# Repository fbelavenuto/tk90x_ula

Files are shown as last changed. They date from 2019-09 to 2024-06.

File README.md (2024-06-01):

# Projeto ULA CPLD - Clone da ULA do TK90X/TK95.

Este projeto se destina a substituir um componente feito sob medida para o microcomputador de 8 bits modelo TK90X e TK95, fabricado pela empresa brasileira Microdigital na década de 1980. O TK90X/TK95 é um clone do ZX Spectrum fabricado pela empresa inglesa Sinclair Research.

# Copyright

Copyright Fábio Belavenuto 2012.
Copyright Victor Trucco 2012.

# Licença

This documentation describes Open Hardware and is licensed under the CERN OHL v. 1.1.
You may redistribute and modify this documentation under the terms of the
CERN OHL v.1.1. (http://ohwr.org/cernohl). This documentation is distributed
WITHOUT ANY EXPRESS OR IMPLIED WARRANTY, INCLUDING OF MERCHANTABILITY,
SATISFACTORY QUALITY AND FITNESS FOR A PARTICULAR PURPOSE.
Please see the CERN OHL v.1.1 for applicable conditions

# Detalhes

Todo este trabalho foi baseado no trabalho do Chris Smith [1] e feito em conjunto pelos autores do projeto. Agradecimentos ao pessoal das listas de discussão brasileiras "ClubedoTK" [2] e "TK90X" [3] que incentivaram e ajudaram no desenvolvimento deste projeto.

No site [4] há um pequeno diário criado pelo Victor Trucco descrevendo os passos durante o desenvolvimento do projeto.

O projeto tem duas revisões, rev1 e rev2, cada uma delas em uma pasta separada. Em cada revisão existem uma pasta com o design da PCB, uma pasta com os aqruivos de fabricação Gerber e uma pasta com o projeto do código-fonte do CPLD. A versão do software utilizado para o design da PCB foi o Cadsoft Eagle e o software utilizado para o design do CPLD foi o Altera Quartus versão 10.1sp1.
  
Na pasta "VHDL Version" há uma versão do código do CPLD toda escrita em VHDL, tanto para CPLDs da Altera e CPLDs da Xilinx. Este código não foi usado no CPLD da ULA final.

Para a revisão 1, o arquivo [Pinout jumpers.jpg] "rev1/Pinout jumpers.jpg" mostra a pinagem dos jumpers e saída RGB contidas na PCB. Para a revisão 2 o mesmo pinout pode ser utilizado, porém a seleção do tipo de sincronismo é feita por jumpers de solda.

O produto final é uma placa pequena feita para ser inserida diretamente no soquete do circuito integrado original, substituindo assim o componente defeituoso, com a vantagem de ter uma saída RGB analógica em 15KHz para ser usado diretamente em monitores compatíveis.

A temporização deste projeto chega a 99% de fidelidade ao componente original.

# Montagem

Para a montagem da PCB, acesse [este](https://fbelavenuto.github.io/pages/ULA-rev1-ibom.html) link para BOM interativo da revisão 1 e [este](https://fbelavenuto.github.io/pages/ULA-rev2-ibom.html) para a revisão 2.

Solde os componentes SMD, consiga uma barra de terminais torneado de 80 pinos, corte-a no meio para os dois lados de 40 pinos. O CPLD ocupa o espaço de quatro pinos da barra de terminais torneada de cada lado, então é necessário cortar os 4 pinos centrais de cada barra para fazer uma soldagem em SMD nestes pontos.

Coloque a barra no lugar para descobrir quais os pinos devem ser cortados, corte com um alicate de corte fino para deixar rente à PCB. Utilize um soquete torneado de 40 pinos e plugue as barras no soquete, para uma soldagem alinhada. Coloque a PCB em cima da barra e encaixe os pinos não cortados nos seus respectivos furos e solde-os. Para soldar os 8 pinos cortados (4 de cada lado) coloque a ponta de ferro em um lado para aquecer a PCB e a barra de pinos ao mesmo tempo e coloque o estanho pelo outro lado. Confira com uma lente se a solda foi bem sucedida.

Se for utilizar a saída RGB 15KHz solde uma barra de pinos 90 graus na PCB, e na revisão 2 solde o jumper de solda do tipo de sincronismo. É possível escolher qual tipo de sincronismo irá para o monitor, separado ou composto. Dependendo do monitor um tipo poderá ser melhor que o outro, então pode ser necessário testar os dois tipos, porém a opção de sincronismo separado tem mais compatibilidade com os monitores.

Na pasta [Fotos](rev1/Fotos/) há algumas fotos do primeiro protótipo construido.

# Programação do CPLD

Para programar o CPLD é necessário um dispositivo USB Blaster específico para os CPLDs da Altera. Na PCB rev1 os pontos de contato dos sinais de programação estão espalhados pela PCB, sendo necessário a construção de uma "cama de pregos" ou a soldagem de fios nos pontos. Para a rev2 os sinais estão dispostos em um conector 1x6. O nome dos sinais estão no silkscreen da PCB. É necessário utilziar uma fonte externa de 5V e jogar 5V no pino VCC do USB Blaster, pois este não alimenta o dispositivo mas detecta se ele está alimentado.

Abra o projeto no software Quartus e vá até o programador. Alimente a PCB e o USB Blaster e clique em "Program". Caso haja falha neste passo cheque as conexões e cheque se está indo os 5V para o USB Blaster. O arquivo necessário para programar se chama "ULA.pof".

# Uso

É altamente recomendável a troca do soquete da ULA na PCB do TK90X/95 por um soquete torneado, porém é possível utilizar o original. Plugue com cuidado a PCB da ULA no soquete do TK, vá pressionando devagar para não entortar nenhum pino. Se tudo ocorrer bem é só ligar o micro e curtir a sua nova ULA.

Se for utilizar a saída RGB 15KHz construa um cabo com um conector DE-15 para ligar nos pinos de saída RGB conforme descrito [nesta](rev1/Pinout%20jumpers.jpg) imagem.

# Links

[1] http://www.zxdesign.info/thebeginning.shtml
[2] http://br.groups.yahoo.com/group/ClubedoTK/
[3] http://br.groups.yahoo.com/group/TK90X/
[4] http://www.victortrucco.com/TK/ULATKCPLD/ULATKCPLD.asp

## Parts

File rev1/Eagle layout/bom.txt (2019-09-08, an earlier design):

Partlist 

Qty Value       Device         Package  Parts              Description                
2   100n        C-EUC1206K     C1206K   C1, C2             CAPACITOR, European symbol 
3   100         R-EU_M0805     M0805    R1, R2, R3         RESISTOR, European symbol  
3   1k5         R-EU_M0805     M0805    R4, R5, R6         RESISTOR, European symbol  
1   10K         R-EU_M0805     M0805    R7                 RESISTOR, European symbol  
1   EPM7128     EPM7128-T100   TQFP100  IC1                EPM70128                   
1   Soquete ULA DIL40          DIL40    IC2                Dual In Line               
1   4050D       4050D          SO16     IC3                Hex non-inverting BUFFER   
1               MA06-11        MA06-1-1 SV1                PIN HEADER                 
4   SELSYNC     MA03-1MA03-1-1 MA03-1-1 SJ1                PIN HEADER

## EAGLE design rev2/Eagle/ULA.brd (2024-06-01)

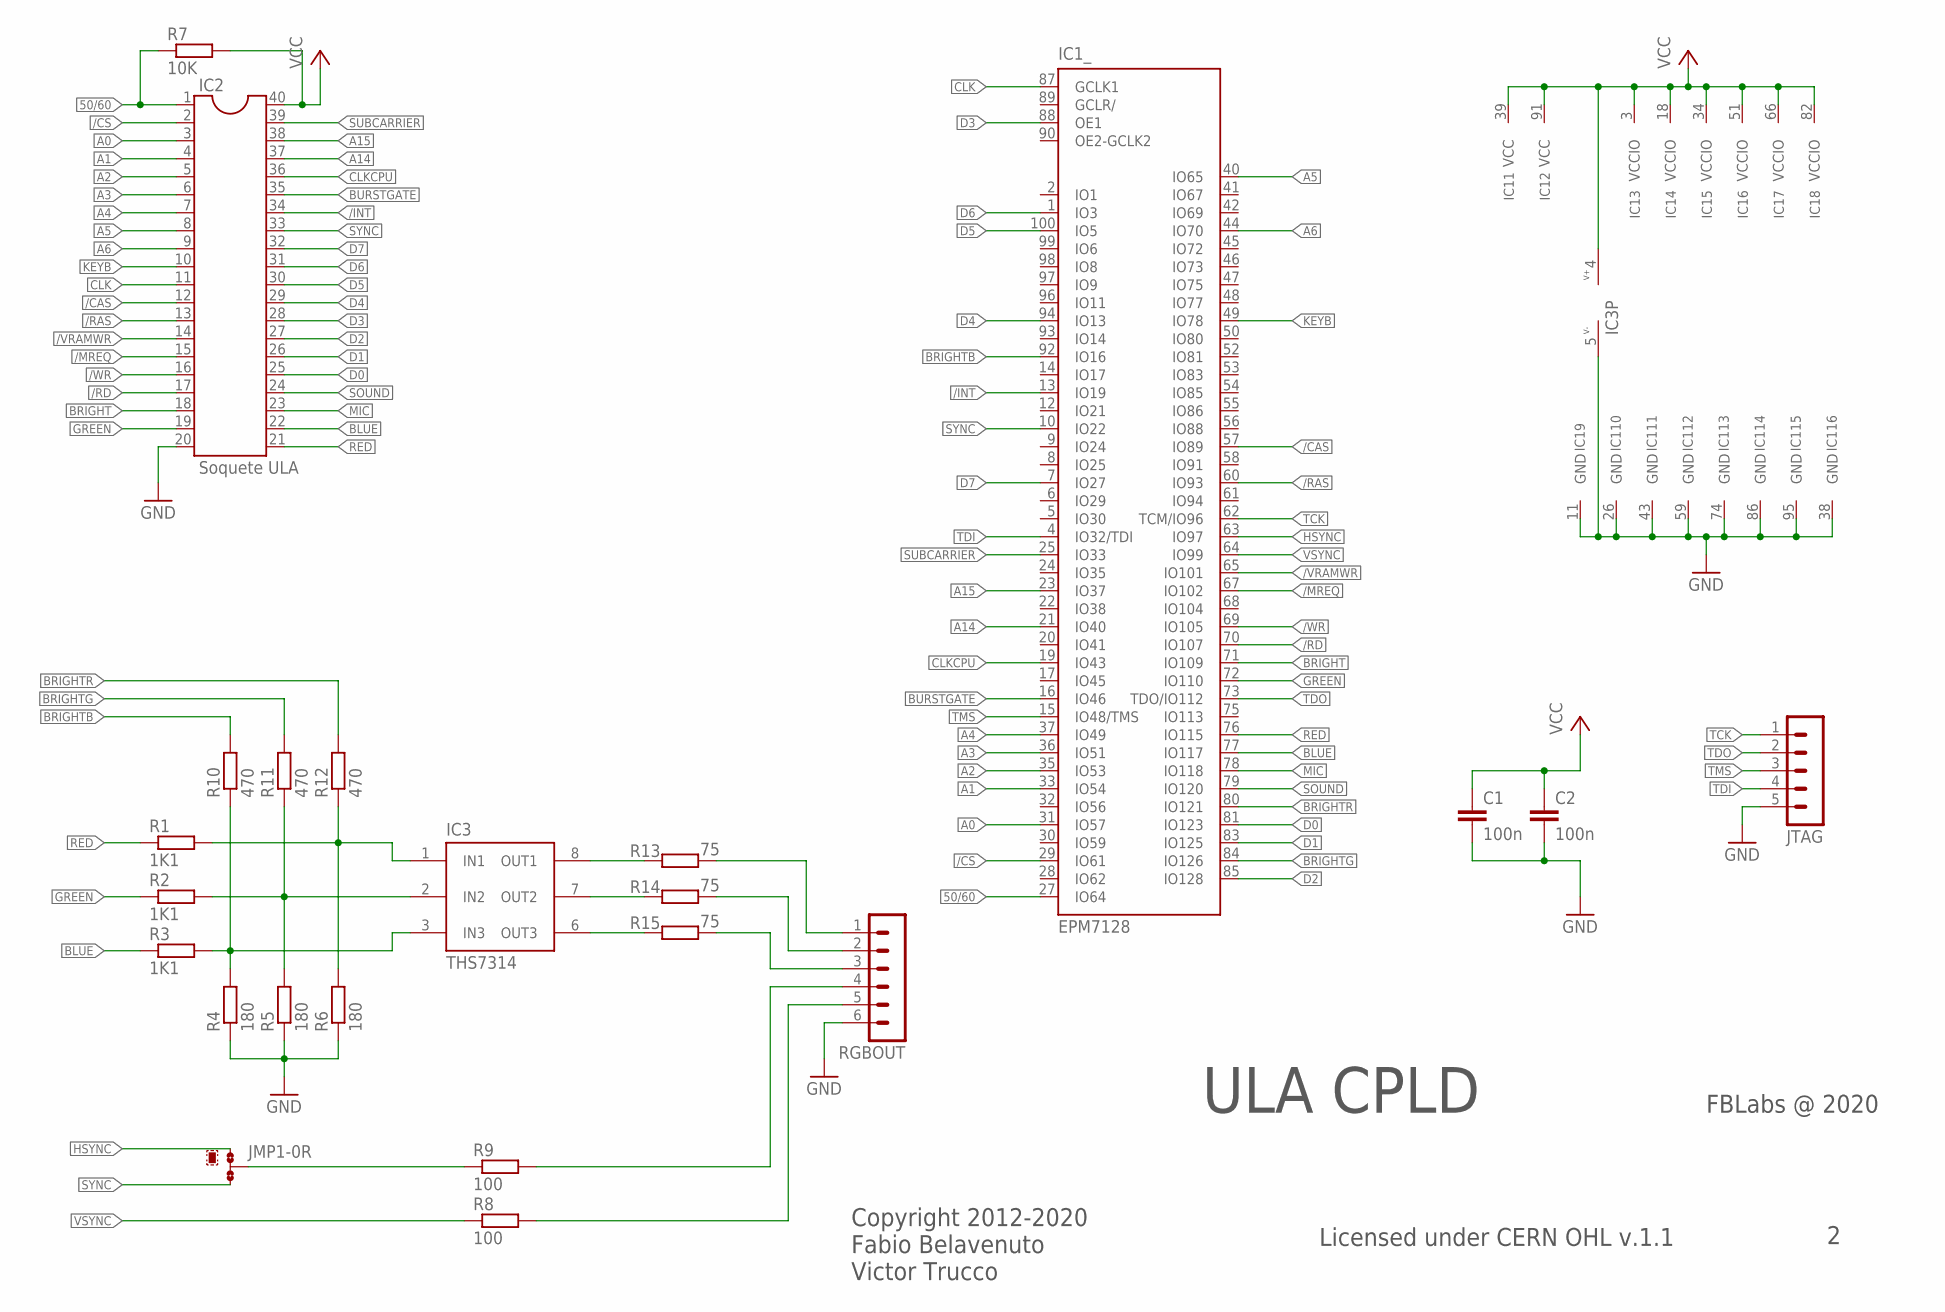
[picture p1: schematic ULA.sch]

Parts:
C1, C2: 100n; C1206
IC1: EPM7128; TQFP100
IC2: Soquete ULA; DIL40
IC3: THS7314; SOIC8
JMP1: 0R-JUMPA; A0R-JMP
JTAG: MA05-1
R1, R2, R3: 1K1; M0805
R4, R5, R6: 180; M0805
R7: 10K; M0805
R8, R9: 100; M0805
R10, R11, R12: 470; M0805
R13, R14, R15: 75; M0805
RGBOUT: MA06-1

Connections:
50/60: IC1.27 (IO64), IC2.1, R7.1
/CAS: IC1.57 (IO89), IC2.12
/CS: IC1.29 (IO61), IC2.2
/INT: IC1.13 (IO19), IC2.34
/MREQ: IC1.67 (IO102), IC2.15
/RAS: IC1.60 (IO93), IC2.13
/RD: IC1.70 (IO107), IC2.17
/VRAMWR: IC1.65 (IO101), IC2.14
/WR: IC1.69 (IO105), IC2.16
A0: IC1.31 (IO57), IC2.3
A1: IC1.33 (IO54), IC2.4
A2: IC1.35 (IO53), IC2.5
A3: IC1.36 (IO51), IC2.6
A4: IC1.37 (IO49), IC2.7
A5: IC1.40 (IO65), IC2.8
A6: IC1.44 (IO70), IC2.9
A14: IC1.21 (IO40), IC2.37
A15: IC1.23 (IO37), IC2.38
BLUE: IC1.77 (IO117), IC2.22, R3.1
BRIGHT: IC1.71 (IO109), IC2.18
BRIGHTB: IC1.92 (IO16), R10.2
BRIGHTG: IC1.84 (IO126), R11.2
BRIGHTR: IC1.80 (IO121), R12.2
BURSTGATE: IC1.16 (IO46), IC2.35
CLK: IC1.87 (GCLK1), IC2.11
CLKCPU: IC1.19 (IO43), IC2.36
D0: IC1.81 (IO123), IC2.25
D1: IC1.83 (IO125), IC2.26
D2: IC1.85 (IO128), IC2.27
D3: IC1.88 (OE1), IC2.28
D4: IC1.94 (IO13), IC2.29
D5: IC1.100 (IO5), IC2.30
D6: IC1.1 (IO3), IC2.31
D7: IC1.7 (IO27), IC2.32
GND: C1.2, C2.2, IC1.11 (GND), IC1.26 (GND), IC1.38 (GND), IC1.43 (GND), IC1.59 (GND), IC1.74 (GND), IC1.86 (GND), IC1.95 (GND), IC2.20, IC3.5 (V-), JTAG.5, R4.1, R5.1, R6.1, RGBOUT.6
GREEN: IC1.72 (IO110), IC2.19, R2.1
HSYNC: IC1.63 (IO97), JMP1.1
KEYB: IC1.49 (IO78), IC2.10
MIC: IC1.78 (IO118), IC2.23
unnamed: R15.2, RGBOUT.3
unnamed: R14.2, RGBOUT.2
unnamed: R13.2, RGBOUT.1
unnamed: IC3.3 (IN3), R3.2, R4.2, R10.1
unnamed: IC3.2 (IN2), R2.2, R5.2, R11.1
unnamed: IC3.6 (OUT3), R15.1
unnamed: IC3.7 (OUT2), R14.1
unnamed: IC3.8 (OUT1), R13.1
unnamed: IC3.1 (IN1), R1.2, R6.2, R12.1
unnamed: JMP1.2, R9.1
unnamed: R9.2, RGBOUT.4
unnamed: R8.2, RGBOUT.5
RED: IC1.76 (IO115), IC2.21, R1.1
SOUND: IC1.79 (IO120), IC2.24
SUBCARRIER: IC1.25 (IO33), IC2.39
SYNC: IC1.10 (IO22), IC2.33, JMP1.3
TCK: IC1.62 (TCM/IO96), JTAG.1
TDI: IC1.4 (IO32/TDI), JTAG.4
TDO: IC1.73 (TDO/IO112), JTAG.2
TMS: IC1.15 (IO48/TMS), JTAG.3
VCC: C1.1, C2.1, IC1.3 (VCCIO), IC1.18 (VCCIO), IC1.34 (VCCIO), IC1.39 (VCC), IC1.51 (VCCIO), IC1.66 (VCCIO), IC1.82 (VCCIO), IC1.91 (VCC), IC2.40, IC3.4 (V+), R7.2
VSYNC: IC1.64 (IO99), R8.1

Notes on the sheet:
ULA CPLD
Licensed under CERN OHL v.1.1
Copyright 2012-2020 Fabio Belavenuto Victor Trucco
FBLabs @ 2020

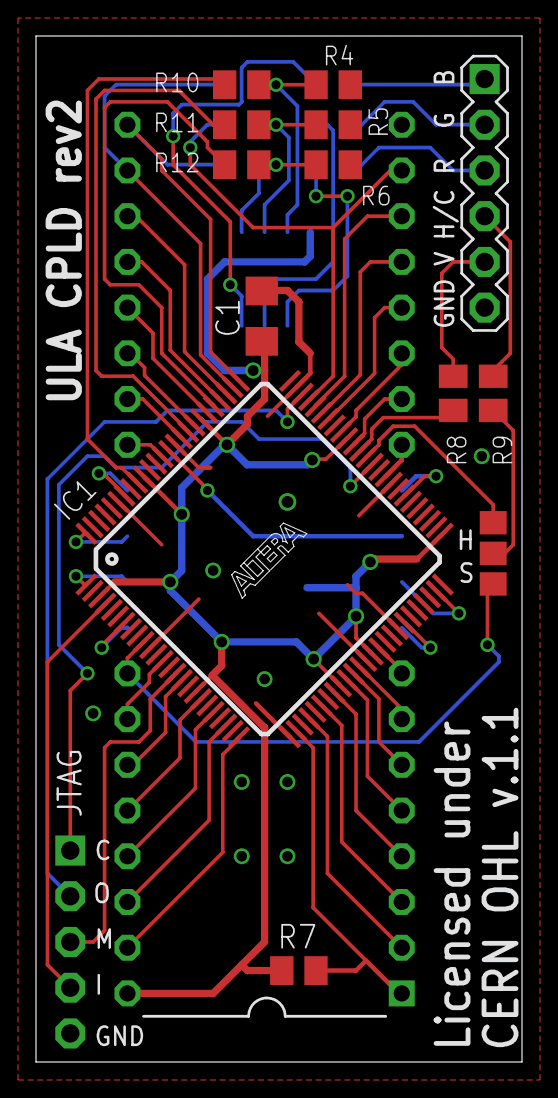
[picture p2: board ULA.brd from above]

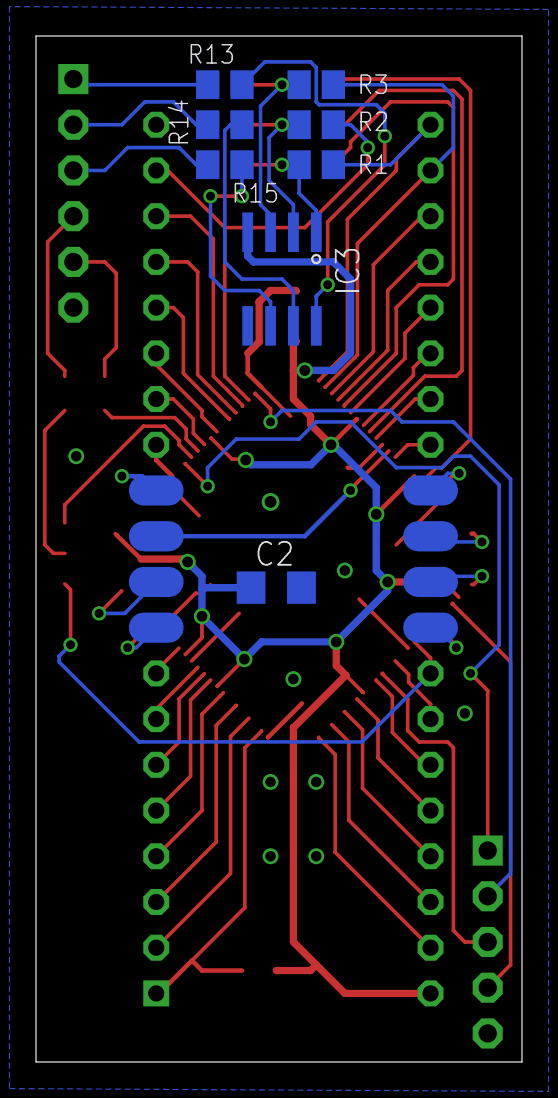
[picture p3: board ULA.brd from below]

Board: 2 copper layers, 27.0 x 57.0 mm, 23 parts (8 on the bottom side), 61 nets.

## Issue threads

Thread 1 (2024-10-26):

ULA Spectrum

FranTerrassa, 2024-10-26:
Olá, ótimo trabalho. Acho ótimo que essa contribuição seja feita para a comunidade. Entendo que este ULA é para um clone do espectro. Poderia funcionar como ULA em um spextrum zx?
Desculpe se não entendi muito bem, estou usando o Google Tradutor.
Saudações,

taupter, 2024-10-29:
Hello. Sadly Fabio Belavenuto took his own life this month. He was a great mind and a great friend that succumbed to depression.
Yes, this ULA can substitute the Ferranti one. It can be configured to work in 50Hz (UK) or 60Hz (PAL-M).

FranTerrassa, 2024-10-29:
ostras!!! você me deixou pedra. Lamento muito ouvir isso, minhas sinceras condolências...

FranTerrassa, 2024-11-21:
> Hola. Lamentablemente Fabio Belavenuto se quitó la vida este mes. Era una gran mente y un gran amigo que sucumbió a la depresión. Sí, este ULA puede sustituir al de Ferranti. Se puede configurar para que funcione en 50 Hz (Reino Unido) o 60 Hz (PAL-M).

como devo fazer isso???

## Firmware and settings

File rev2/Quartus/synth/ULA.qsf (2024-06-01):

# -------------------------------------------------------------------------- #
#
# Copyright (C) 1991-2011 Altera Corporation
# Your use of Altera Corporation's design tools, logic functions 
# and other software and tools, and its AMPP partner logic 
# functions, and any output files from any of the foregoing 
# (including device programming or simulation files), and any 
# associated documentation or information are expressly subject 
# to the terms and conditions of the Altera Program License 
# Subscription Agreement, Altera MegaCore Function License 
# Agreement, or other applicable license agreement, including, 
# without limitation, that your use is for the sole purpose of 
# programming logic devices manufactured by Altera and sold by 
# Altera or its authorized distributors.  Please refer to the 
# applicable agreement for further details.
#
# -------------------------------------------------------------------------- #
#
# Quartus II 64-Bit
# Version 10.1 Build 197 01/19/2011 Service Pack 1 SJ Web Edition
# Date created = 20:05:27  May 17, 2013
#
# -------------------------------------------------------------------------- #
#
# Notes:
#
# 1) The default values for assignments are stored in the file:
#		ULA_assignment_defaults.qdf
#    If this file doesn't exist, see file:
#		assignment_defaults.qdf
#
# 2) Altera recommends that you do not modify this file. This
#    file is updated automatically by the Quartus II software
#    and any changes you make may be lost or overwritten.
#
# -------------------------------------------------------------------------- #


set_global_assignment -name FAMILY MAX7000S
set_global_assignment -name DEVICE "EPM7128STC100-15"
set_global_assignment -name TOP_LEVEL_ENTITY ULA
set_global_assignment -name ORIGINAL_QUARTUS_VERSION "10.1 SP1"
set_global_assignment -name PROJECT_CREATION_TIME_DATE "20:05:27  MAY 17, 2013"
set_global_assignment -name LAST_QUARTUS_VERSION "13.0 SP1"
set_global_assignment -name DEVICE_FILTER_PACKAGE TQFP
set_global_assignment -name DEVICE_FILTER_PIN_COUNT 100
set_global_assignment -name ERROR_CHECK_FREQUENCY_DIVISOR 1702130533
set_global_assignment -name MIN_CORE_JUNCTION_TEMP 0
set_global_assignment -name MAX_CORE_JUNCTION_TEMP 85
set_global_assignment -name EDA_SIMULATION_TOOL "ModelSim-Altera (VHDL)"
set_global_assignment -name EDA_OUTPUT_DATA_FORMAT VHDL -section_id eda_simulation
set_global_assignment -name MAX7000_DEVICE_IO_STANDARD TTL
set_global_assignment -name PROJECT_OUTPUT_DIRECTORY output_files
set_global_assignment -name BDF_FILE ../src/Wait_Subcarrier.bdf
set_global_assignment -name BDF_FILE ../src/ULA.bdf
set_global_assignment -name BDF_FILE ../src/Porta254.bdf
set_global_assignment -name BDF_FILE ../src/HSync_Blank.bdf
set_global_assignment -name BDF_FILE ../src/DRAM_CAS_RAS.bdf
set_global_assignment -name BDF_FILE ../src/DRAM_ADDRESS.bdf
set_global_assignment -name BDF_FILE ../src/Display.bdf
set_global_assignment -name BDF_FILE ../src/clock.bdf
set_global_assignment -name VERILOG_FILE ../src/interrupcao2.v
set_global_assignment -name VERILOG_FILE ../src/counter_9bit.v
set_global_assignment -name VERILOG_FILE ../src/counter_13bit.v
set_global_assignment -name VERILOG_FILE ../src/counter_12bit.v
set_global_assignment -name VERILOG_FILE ../src/counter_10bit.v
set_global_assignment -name VHDL_FILE ../src/VSync2.vhd
set_global_assignment -name VHDL_FILE ../src/VoutGen.vhd
set_location_assignment PIN_7 -to d[7]
set_location_assignment PIN_1 -to d[6]
set_location_assignment PIN_100 -to d[5]
set_location_assignment PIN_94 -to d[4]
set_location_assignment PIN_88 -to d[3]
set_location_assignment PIN_85 -to d[2]
set_location_assignment PIN_83 -to d[1]
set_location_assignment PIN_81 -to d[0]
set_location_assignment PIN_27 -to PINO1_60/50Hz
set_location_assignment PIN_29 -to PINO2_/CS
set_location_assignment PIN_31 -to PINO3_A0
set_location_assignment PIN_33 -to PINO4_A1
set_location_assignment PIN_35 -to PINO5_A2
set_location_assignment PIN_36 -to PINO6_A3
set_location_assignment PIN_37 -to PINO7_A4
set_location_assignment PIN_40 -to PINO8_A5
set_location_assignment PIN_44 -to PINO9_A6
set_location_assignment PIN_49 -to PINO10_KEYBOARD
set_location_assignment PIN_87 -to PINO11_CLK
set_location_assignment PIN_57 -to PINO12_/CAS
set_location_assignment PIN_60 -to PINO13_/RAS
set_location_assignment PIN_65 -to PINO14_/VRAMWR
set_location_assignment PIN_67 -to PINO15_/MREQ
set_location_assignment PIN_69 -to PINO16_/WR
set_location_assignment PIN_70 -to PINO17_/RD
set_location_assignment PIN_71 -to PINO18_BRIGHT
set_location_assignment PIN_72 -to PINO19_GREEN
set_location_assignment PIN_76 -to PINO21_RED
set_location_assignment PIN_77 -to PINO22_BLUE
set_location_assignment PIN_78 -to PINO23_MIC
set_location_assignment PIN_79 -to PINO24_SOUND
set_location_assignment PIN_10 -to PINO33_SYNC
set_location_assignment PIN_13 -to PINO34_/INT
set_location_assignment PIN_16 -to PINO35_BURSTGATE
set_location_assignment PIN_19 -to PINO36_CLKCPU
set_location_assignment PIN_21 -to PINO37_A14
set_location_assignment PIN_23 -to PINO38_A15
set_location_assignment PIN_25 -to PINO39_SUBCARRIER
set_location_assignment PIN_63 -to _HSYNC
set_location_assignment PIN_64 -to _VSYNC
set_location_assignment PIN_92 -to BRIGHTB
set_location_assignment PIN_84 -to BRIGHTG
set_location_assignment PIN_80 -to BRIGHTR

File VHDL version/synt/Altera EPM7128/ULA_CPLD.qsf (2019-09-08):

# -------------------------------------------------------------------------- #
#
# Copyright (C) 1991-2013 Altera Corporation
# Your use of Altera Corporation's design tools, logic functions 
# and other software and tools, and its AMPP partner logic 
# functions, and any output files from any of the foregoing 
# (including device programming or simulation files), and any 
# associated documentation or information are expressly subject 
# to the terms and conditions of the Altera Program License 
# Subscription Agreement, Altera MegaCore Function License 
# Agreement, or other applicable license agreement, including, 
# without limitation, that your use is for the sole purpose of 
# programming logic devices manufactured by Altera and sold by 
# Altera or its authorized distributors.  Please refer to the 
# applicable agreement for further details.
#
# -------------------------------------------------------------------------- #
#
# Quartus II 64-Bit
# Version 13.0.1 Build 232 06/12/2013 Service Pack 1 SJ Web Edition
# Date created = 17:55:27  November 14, 2013
#
# -------------------------------------------------------------------------- #
#
# Notes:
#
# 1) The default values for assignments are stored in the file:
#		ULA_CPLD_assignment_defaults.qdf
#    If this file doesn't exist, see file:
#		assignment_defaults.qdf
#
# 2) Altera recommends that you do not modify this file. This
#    file is updated automatically by the Quartus II software
#    and any changes you make may be lost or overwritten.
#
# -------------------------------------------------------------------------- #


set_global_assignment -name FAMILY MAX7000S
set_global_assignment -name DEVICE "EPM7128STC100-10"
set_global_assignment -name TOP_LEVEL_ENTITY ula
set_global_assignment -name ORIGINAL_QUARTUS_VERSION "13.0 SP1"
set_global_assignment -name PROJECT_CREATION_TIME_DATE "17:55:26  NOVEMBER 14, 2013"
set_global_assignment -name LAST_QUARTUS_VERSION "13.0 SP1"
set_global_assignment -name PROJECT_OUTPUT_DIRECTORY output_files
set_global_assignment -name DEVICE_FILTER_PACKAGE TQFP
set_global_assignment -name DEVICE_FILTER_PIN_COUNT 100
set_global_assignment -name ERROR_CHECK_FREQUENCY_DIVISOR "-1"
set_global_assignment -name OPTIMIZE_HOLD_TIMING OFF
set_global_assignment -name OPTIMIZE_MULTI_CORNER_TIMING OFF
set_global_assignment -name FITTER_EFFORT "STANDARD FIT"
set_global_assignment -name VHDL_FILE ../../src/ula.vhd
set_global_assignment -name VHDL_FILE ../../src/top.vhd
set_global_assignment -name EDA_SIMULATION_TOOL "ModelSim-Altera (VHDL)"
set_global_assignment -name EDA_OUTPUT_DATA_FORMAT VHDL -section_id eda_simulation
set_global_assignment -name MAX7000_DEVICE_IO_STANDARD TTL
set_location_assignment PIN_7 -to ULA_D[7]
set_location_assignment PIN_1 -to ULA_D[6]
set_location_assignment PIN_100 -to ULA_D[5]
set_location_assignment PIN_94 -to ULA_D[4]
set_location_assignment PIN_88 -to ULA_D[3]
set_location_assignment PIN_85 -to ULA_D[2]
set_location_assignment PIN_83 -to ULA_D[1]
set_location_assignment PIN_81 -to ULA_D[0]
set_location_assignment PIN_27 -to VERT50_60
set_location_assignment PIN_69 -to WR
set_location_assignment PIN_77 -to BLUE
set_location_assignment PIN_71 -to BRIGHT
set_location_assignment PIN_16 -to BURSTGATE
set_location_assignment PIN_19 -to CPU
set_location_assignment PIN_10 -to CSYNC
set_location_assignment PIN_72 -to GREEN
set_location_assignment PIN_63 -to HSYNC
set_location_assignment PIN_13 -to INT
set_location_assignment PIN_49 -to KEYBOARD
set_location_assignment PIN_78 -to MIC
set_location_assignment PIN_76 -to RED
set_location_assignment PIN_79 -to SOUND
set_location_assignment PIN_25 -to SUBCARRIER
set_location_assignment PIN_44 -to VRAM_A[6]
set_location_assignment PIN_40 -to VRAM_A[5]
set_location_assignment PIN_37 -to VRAM_A[4]
set_location_assignment PIN_36 -to VRAM_A[3]
set_location_assignment PIN_35 -to VRAM_A[2]
set_location_assignment PIN_33 -to VRAM_A[1]
set_location_assignment PIN_31 -to VRAM_A[0]
set_location_assignment PIN_57 -to VRAM_CAS
set_location_assignment PIN_60 -to VRAM_RAS
set_location_assignment PIN_65 -to VRAM_WR
set_location_assignment PIN_64 -to VSYNC
set_location_assignment PIN_21 -to A14
set_location_assignment PIN_23 -to A15
set_location_assignment PIN_29 -to CS
set_location_assignment PIN_67 -to MREQ
set_location_assignment PIN_87 -to OSC
set_location_assignment PIN_70 -to RD
set_global_assignment -name MAX7000_OPTIMIZATION_TECHNIQUE SPEED
set_global_assignment -name SYNTH_TIMING_DRIVEN_SYNTHESIS OFF

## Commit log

2019-09-08 First upload
    [ULA.brd, ULA.sch]
2024-06-01 Organização e documentação
    [ULA.GBL, ULA.GBO, ULA.GBS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]
